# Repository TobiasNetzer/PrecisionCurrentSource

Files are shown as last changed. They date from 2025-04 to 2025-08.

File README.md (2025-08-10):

## A precision current source that can be configured for currents up to ~10mA.

I needed to verify the current measurement accuracy of the low-current ranges of my data logger and a reference for calibration purposes. Since I don’t own a programmable current source like a Keithley 220 or SMU, I came up with this approach instead. Check [here](https://tobiasnetzer.github.io/posts/current-source/) for more info.

Documentation
- [Schematic](https://github.com/TobiasNetzer/PrecisionCurrentSource/blob/main/Documentation/Schematic.pdf)
- [Assembly Drawing](https://github.com/TobiasNetzer/PrecisionCurrentSource/blob/main/Documentation/Assembly%20Drawing.pdf)
- [BOM](https://htmlpreview.github.io/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)

---

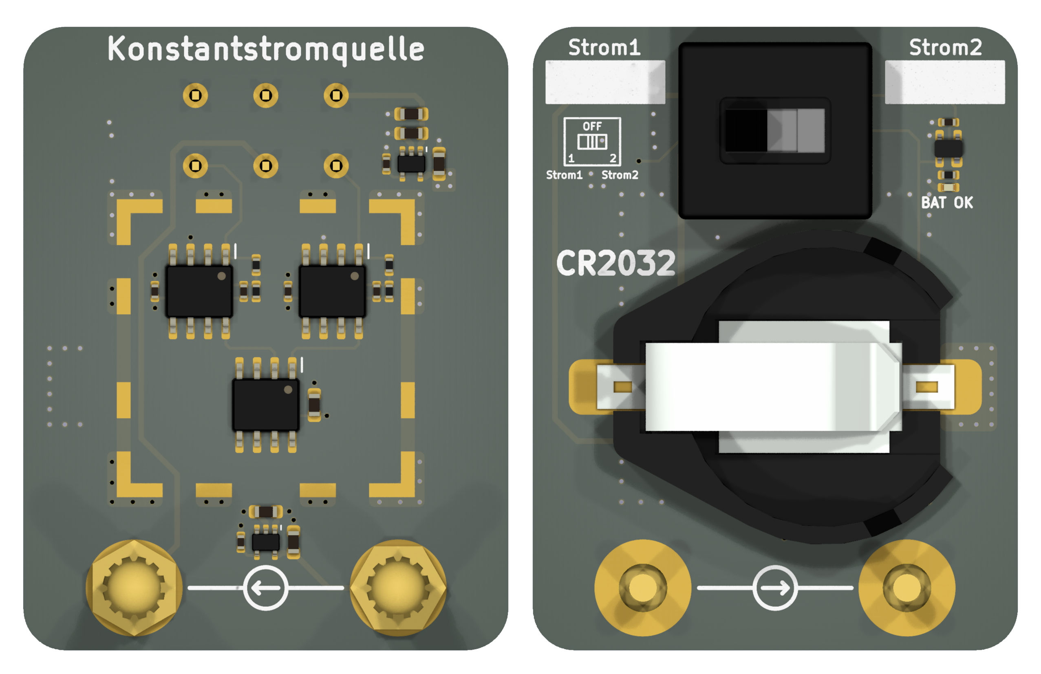
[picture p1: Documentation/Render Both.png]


## Limitations of the Design

Due to the high internal resistance of CR2032 coin cells, they are unable to deliver currents higher than approximately 15mA. This inherently limits the maximum output of the constant current source. However, it's not the only limiting factor. The op-amp used in the circuit can only sink up to 15mA, making the current source only suitable for output currents up to around 10mA.  

In addition, the voltage swing across the load is limited to 1.4V. For example, at a current of 1mA, the maximum  load is limited to 1.4kΩ. This further restricts the usable range of the current source.

These limitations should be taken into account when using this current source!

## First Tests

The design has not been fully tested yet! The output current has been measured to be within ±0.2%.

| Configured Current &nbsp; &nbsp; &nbsp; &nbsp; &nbsp; &nbsp; | Measured Current &nbsp; &nbsp; &nbsp; &nbsp; &nbsp; &nbsp; | Error &nbsp; &nbsp; &nbsp; &nbsp; &nbsp; &nbsp; |
| --- | --- | --- |
| 100nA | 99.82nA | -0.18% |
| 1µA | 0.999µA | -0.1% |
| 100µA | 100.07µA | 0.07% |
| 1mA | 0.999mA | -0.1% |

Several other aspects such as load regulation, temperature stability and ripple/noise should also be tested. However, I currently lack the equipment to accurately perform these tests.

I did sample the output current with my datalogger at 1kHz to get an idea of how noisy the current source is. These results should be taken with a grain of salt, since the logger’s ADC does some internal averaging and I don't have a known reference to test the logger against.

| Current Source &nbsp; &nbsp; &nbsp; &nbsp; &nbsp; &nbsp; | Peak-Peak Current &nbsp; &nbsp; &nbsp; &nbsp; &nbsp; &nbsp; |
| --- | --- |
| 1µA | 1.23nA |
| 100µA | 73.25nA |
| 1mA | 1.24µA |

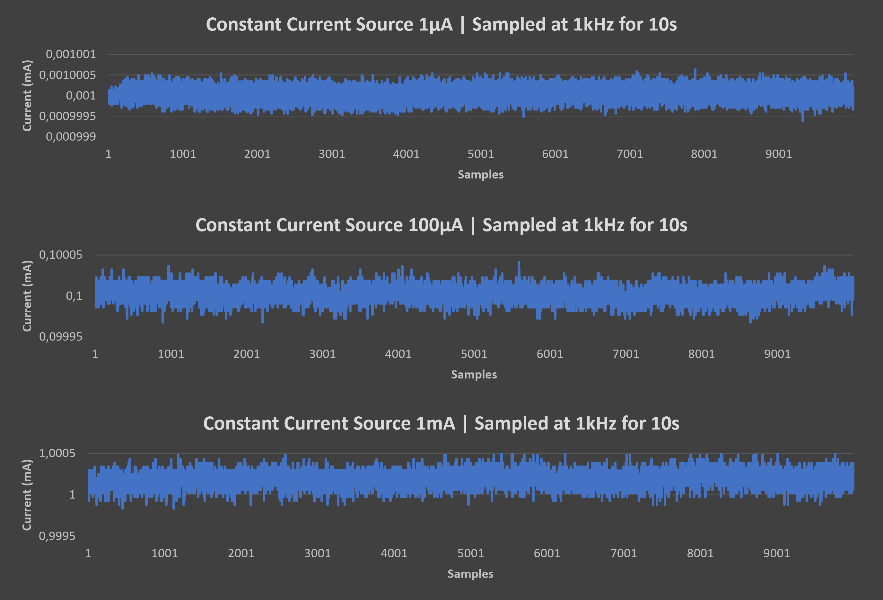
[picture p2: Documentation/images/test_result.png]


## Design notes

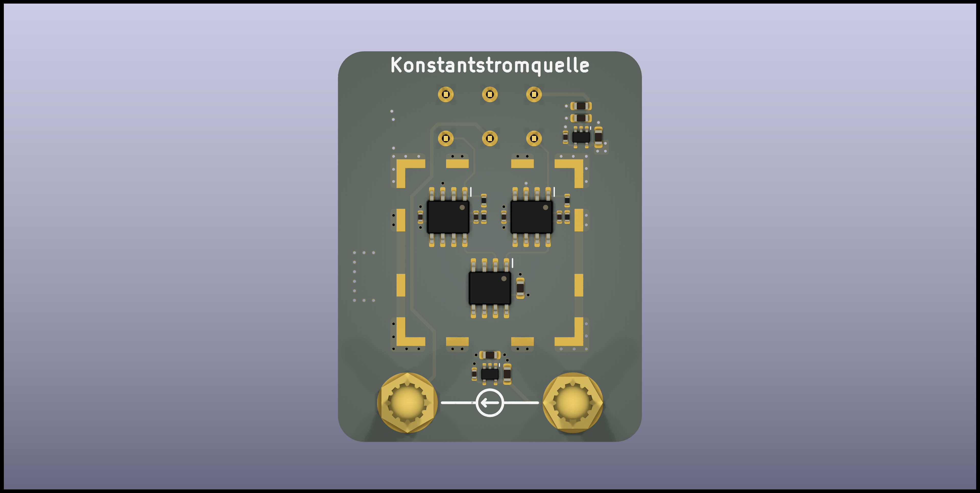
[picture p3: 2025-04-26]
Documentation/Render Top.png

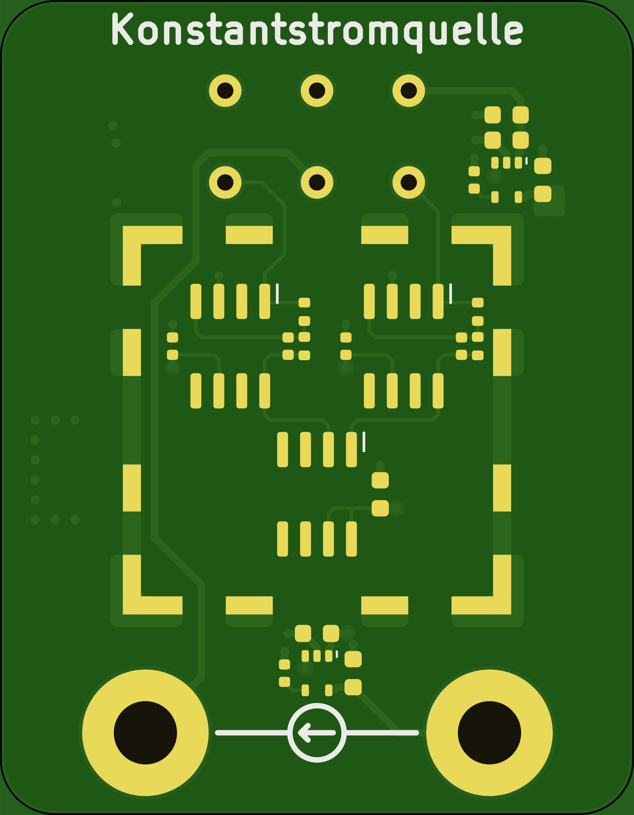
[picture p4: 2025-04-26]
Documentation/plot/PrecisionCurrentSource-Front.png

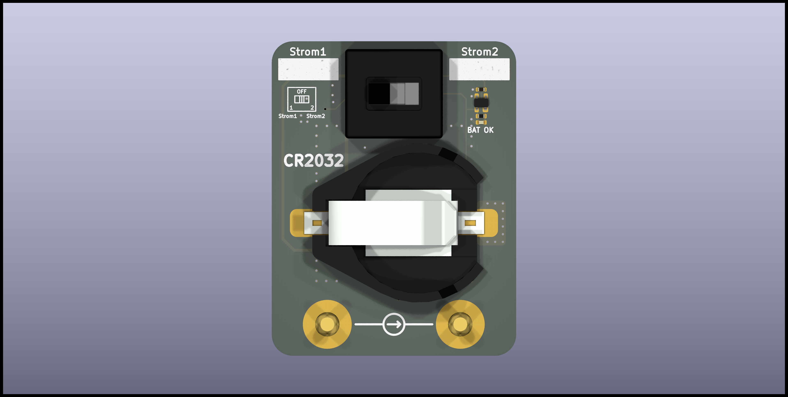
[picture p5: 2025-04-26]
Documentation/Render Bot.png

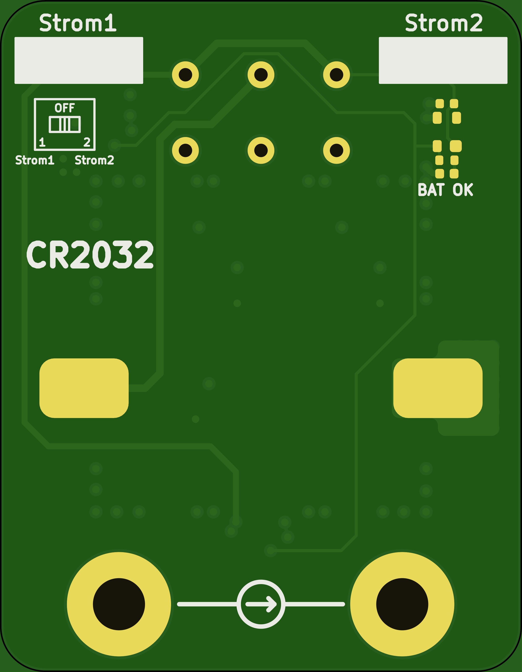
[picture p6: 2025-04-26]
Documentation/plot/PrecisionCurrentSource-Back.png

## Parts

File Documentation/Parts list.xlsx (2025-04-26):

Position | Menge | Reference(s) | Wert/Typ | Beschreibung | Hersteller | Hersteller-Nr. | Lieferant | Lieferant-Nr. | Stückpreis | Gesamtpreis
1 | 1 | BT1 | 2x CR2032 | Coin Cell Battery Holders 2X20MM SMT COIN HOLDER | Keystone Electronics | 1062 | Mouser | 534-1062 | 3.02 € | 3.02 €
2 | 2 | C1, C13 | 10µF | 10µF-20%-0603-X5R-10V | Kemet | C0603C106M8PACTU | Mouser | 80-C0603C106M8PACTU | 0.43 € | 0.86 €
3 | 3 | C2, C3, C5 | 100nF | 100nF-20%-0402-X7R-25V | Kemet | C0402C104M3RACTU | Mouser | 80-C0402C104M3R | 0.26 € | 0.78 €
4 | 4 | C4, C6, C8, C11 | 10nF | 10nF-10%-0402-X7R-50V | Kemet | C0402C103K5REC7411 | Mouser | 80-C0402C103K5RECLR | 0.10 € | 0.40 €
5 | 4 | C7, C9, C10, C12 | 1µF | 1µF-10%-0603-X7R-25V | Kemet | C0603C105K3RACTU | Mouser | 80-C0603C105K3R | 0.26 € | 1.04 €
6 | 1 | D1 | Green | LED Green 0402 | Kingbright | APHHS1005ZGC | Mouser | 604-APHHS1005ZGC | 0.66 € | 0.66 €
7 | 1 | J1 | EMI-Shield | EMI Gaskets, Sheets, Absorbers & Shielding WE-SHC SMD Frame 21x21mm | Würth Elektronik | 36103205 | Mouser | 710-36103205 | 2.90 € | 2.90 €
8 | 1 | R1 | 8k2 | 8k2-1%-0402-62.5mW-100ppm | Yageo | AC0402FR-138K2L | Mouser | 603-AC0402FR-138K2L | 0.09 € | 0.09 €
9 | 2 | R2, R4 | 1k 0,05% | 1k-0.05%-0402-62.5mW-5ppm | Susumu | RG1005V-102-W-T1 | Mouser | 754-RG1005V-102-WT1 | 3.12 € | 6.24 €
10 | 1 | R3 | 1M 0,1% | 1M-0.1%-0402-100mW-25ppm | Vishay | MCS0402MD1004BE000 | Mouser | 594-MCS0402MD1004BE0 | 0.66 € | 0.66 €
11 | 1 | R5 | 100k 0,05% | 100k-0.05%-0402-62.5mW-10ppm | Vishay | TNPU0402100KAYEP00 | Mouser | 71-TNPU0402100KAYEP0 | 1.56 € | 1.56 €
12 | 1 | SW1 | 600DP3S2M4R | Schiebeschalter DPDT Durchkontaktierung | E-Switch | 600DP3S2M4R | Digikey | 600DP3S2M4R-ND | 2.29 € | 2.29 €
13 | 1 | U1 | BU4947F | Supervisory Circuits IC CMOS VOLT DETECT | ROHM Semiconductor | BU4947F-TR | Mouser | 755-BU4947F-TR | 0.54 € | 0.54 €
14 | 2 | U2, U3 | LMP7721 | Präzisionsverstärker 3 FEMTOAMPERE INPUT BIAS CURR PREC AMP | Texas Instruments | LMP7721MA/NOPB | Mouser | 926-LMP7721MA/NOPB | 6.12 € | 12.24 €
15 | 1 | U4 | REF200AU | Strom- und Leistungswächter und -regler Dual Current Source Current Sink | Texas Instruments | REF200AU | Mouser | 595-REF200AU | 11.01 € | 11.01 €
16 | 1 | U5 | TPS71745 | LDO Voltage Regulators AC SGL Out LDO 150mA Fixed High PSRR | Texas Instruments | TPS71745QDCKRQ1 | Mouser | 595-TPS71745QDCKRQ1 | 1.44 € | 1.44 €
17 | 1 | U6 | TPS71715 | LDO Spannungs-Regulator LN High-BW PSRR 150mA | Texas Instruments | TPS71715DCKT | Mouser | 595-TPS71715DCKT | 1.46 € | 1.46 €
 |  |  |  |  |  |  |  |  |  | 47.19 €

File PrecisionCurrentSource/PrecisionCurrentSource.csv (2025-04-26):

Source: | X:\TA\Precision Current Source\PrecisionCurrentSource\PrecisionCurrentSource.kicad_sch
Date: | 19/04/2022 01:20:49
Tool: | Eeschema (6.0.4)
Generator: | C:\Program Files\KiCad\6.0\bin\scripting\plugins/bom_csv_grouped_by_value.py
Component Count: | 30
Individual Components:
Item | Qty | Reference(s) | Value | LibPart | Footprint | Datasheet | Beschreibung | Hersteller | Hersteller-Nr. | Lieferant | Lieferant-Nr.
 |  | BT1 | 2x CR2032 | PrecisionCurrentSource:Battery_Holder_1062 | PrecisionCurrentSource:Keystone_1062 | https://eu.mouser.com/datasheet/2/215/1062-745917.pdf | Coin Cell Battery Holders 2X20MM SMT COIN HOLDER | Keystone Electronics | 1062 | Mouser | 534-1062
 |  | C1 | 10µF | PrecisionCurrentSource:Capacitor_0603 | PrecisionCurrentSource:Capacitor_0603 | ~ | 10µF-20%-0603-X5R-10V | Kemet | C0603C106M8PACTU | Mouser | 80-C0603C106M8PACTU
 |  | C2 | 100nF | PrecisionCurrentSource:Capacitor_0402 | PrecisionCurrentSource:Capacitor_0402 | ~ | 100nF-20%-0402-X7R-25V | Kemet | C0402C104M3RACTU | Mouser | 80-C0402C104M3R
 |  | C3 | 100nF | PrecisionCurrentSource:Capacitor_0402 | PrecisionCurrentSource:Capacitor_0402 | ~ | 100nF-20%-0402-X7R-25V | Kemet | C0402C104M3RACTU | Mouser | 80-C0402C104M3R
 |  | C4 | 10nF | PrecisionCurrentSource:Capacitor_0402 | PrecisionCurrentSource:Capacitor_0402 | ~ | 10nF-10%-0402-X7R-50V | Kemet | C0402C103K5REC7411 | Mouser | 80-C0402C103K5RECLR
 |  | C5 | 100nF | PrecisionCurrentSource:Capacitor_0402 | PrecisionCurrentSource:Capacitor_0402 | ~ | 100nF-20%-0402-X7R-25V | Kemet | C0402C104M3RACTU | Mouser | 80-C0402C104M3R
 |  | C6 | 10nF | PrecisionCurrentSource:Capacitor_0402 | PrecisionCurrentSource:Capacitor_0402 | ~ | 10nF-10%-0402-X7R-50V | Kemet | C0402C103K5REC7411 | Mouser | 80-C0402C103K5RECLR
 |  | C7 | 1µF | PrecisionCurrentSource:Capacitor_0603 | PrecisionCurrentSource:Capacitor_0603 | ~ | 1µF-10%-0603-X7R-25V | Kemet | C0603C105K3RACTU | Mouser | 80-C0603C105K3R
 |  | C8 | 10nF | PrecisionCurrentSource:Capacitor_0402 | PrecisionCurrentSource:Capacitor_0402 | ~ | 10nF-10%-0402-X7R-50V | Kemet | C0402C103K5REC7411 | Mouser | 80-C0402C103K5RECLR
 |  | C9 | 1µF | PrecisionCurrentSource:Capacitor_0603 | PrecisionCurrentSource:Capacitor_0603 | ~ | 1µF-10%-0603-X7R-25V | Kemet | C0603C105K3RACTU | Mouser | 80-C0603C105K3R
 |  | C10 | 1µF | PrecisionCurrentSource:Capacitor_0603 | PrecisionCurrentSource:Capacitor_0603 | ~ | 1µF-10%-0603-X7R-25V | Kemet | C0603C105K3RACTU | Mouser | 80-C0603C105K3R
 |  | C11 | 10nF | PrecisionCurrentSource:Capacitor_0402 | PrecisionCurrentSource:Capacitor_0402 | ~ | 10nF-10%-0402-X7R-50V | Kemet | C0402C103K5REC7411 | Mouser | 80-C0402C103K5RECLR
 |  | C12 | 1µF | PrecisionCurrentSource:Capacitor_0603 | PrecisionCurrentSource:Capacitor_0603 | ~ | 1µF-10%-0603-X7R-25V | Kemet | C0603C105K3RACTU | Mouser | 80-C0603C105K3R
 |  | C13 | 10µF | PrecisionCurrentSource:Capacitor_0603 | PrecisionCurrentSource:Capacitor_0603 | ~ | 10µF-20%-0603-X5R-10V | Kemet | C0603C106M8PACTU | Mouser | 80-C0603C106M8PACTU
 |  | D1 | Green | PrecisionCurrentSource:LED_0402 | PrecisionCurrentSource:LED_0402 | ~ | LED Green 0402 | Kingbright | APHHS1005ZGC | Mouser | 604-APHHS1005ZGC
 |  | H1 | MountingHole | PrecisionCurrentSource:MountingHole | PrecisionCurrentSource:MountingHole | ~
 |  | H2 | MountingHole | PrecisionCurrentSource:MountingHole | PrecisionCurrentSource:MountingHole | ~
 |  | J1 | EMI-Shield | :EMI_Shield_1 | PrecisionCurrentSource:Wuerth_36103205_20x20mm | https://www.mouser.de/datasheet/2/445/36103205-1716387.pdf | EMI Gaskets, Sheets, Absorbers & Shielding WE-SHC SMD Frame 21x21mm | Würth Elektronik | 36103205 | Mouser | 710-36103205
 |  | R1 | 8k2 | PrecisionCurrentSource:Resistor_0402 | PrecisionCurrentSource:Resistor_0402 | ~ | 8k2-1%-0402-62.5mW-100ppm | Yageo | AC0402FR-138K2L | Mouser | 603-AC0402FR-138K2L
 |  | R2 | 1k 0,05% | PrecisionCurrentSource:Resistor_0402 | PrecisionCurrentSource:Resistor_0402 | ~ | 1k-0.05%-0402-62.5mW-5ppm | Susumu | RG1005V-102-W-T1 | Mouser | 754-RG1005V-102-WT1
 |  | R3 | 1M 0,1% | PrecisionCurrentSource:Resistor_0402 | PrecisionCurrentSource:Resistor_0402 | ~ | 1M-0.1%-0402-100mW-25ppm | Vishay | MCS0402MD1004BE000 | Mouser | 594-MCS0402MD1004BE0
 |  | R4 | 1k 0,05% | PrecisionCurrentSource:Resistor_0402 | PrecisionCurrentSource:Resistor_0402 | ~ | 1k-0.05%-0402-62.5mW-5ppm | Susumu | RG1005V-102-W-T1 | Mouser | 754-RG1005V-102-WT1
 |  | R5 | 100k 0,05% | PrecisionCurrentSource:Resistor_0402 | PrecisionCurrentSource:Resistor_0402 | ~ | 100k-0.05%-0402-62.5mW-10ppm | Vishay | TNPU0402100KAYEP00 | Mouser | 71-TNPU0402100KAYEP0
 |  | SW1 | 600DP3S2M4R | PrecisionCurrentSource:600DP3S2M4R | PrecisionCurrentSource:600DP3S2M4R | http://spec_sheets.e-switch.com/specs/T620307.pdf | Schiebeschalter DPDT Durchkontaktierung | E-Switch | 600DP3S2M4R | Digikey | 600DP3S2M4R-ND
 |  | U1 | BU4947F | PrecisionCurrentSource:BU4947F | PrecisionCurrentSource:SOP4 | https://www.mouser.de/datasheet/2/348/bu48xxg_e-1874410.pdf | Supervisory Circuits IC CMOS VOLT DETECT | ROHM Semiconductor | BU4947F-TR | Mouser | 755-BU4947F-TR
 |  | U2 | LMP7721 | PrecisionCurrentSource:LMP7721 | PrecisionCurrentSource:SOIC-8 | https://www.ti.com/lit/ds/symlink/lmp7721.pdf?HQS=dis-mous-null-mousermode-dsf-pf-null-wwe&ts=1633781774392 | Präzisionsverstärker 3 FEMTOAMPERE INPUT BIAS CURR PREC AMP | Texas Instruments | LMP7721MA/NOPB | Mouser | 926-LMP7721MA/NOPB
 |  | U3 | LMP7721 | PrecisionCurrentSource:LMP7721 | PrecisionCurrentSource:SOIC-8 | https://www.ti.com/lit/ds/symlink/lmp7721.pdf?HQS=dis-mous-null-mousermode-dsf-pf-null-wwe&ts=1633781774392 | Präzisionsverstärker 3 FEMTOAMPERE INPUT BIAS CURR PREC AMP | Texas Instruments | LMP7721MA/NOPB | Mouser | 926-LMP7721MA/NOPB
 |  | U4 | REF200AU | PrecisionCurrentSource:REF200AU | PrecisionCurrentSource:SOIC-8 | https://www.ti.com/lit/ds/symlink/ref200.pdf?ts=1633768165003 | Strom- und Leistungswächter und -regler Dual Current Source Current Sink | Texas Instruments | REF200AU | Mouser | 595-REF200AU
 |  | U5 | TPS71745 | PrecisionCurrentSource:TPS71745 | PrecisionCurrentSource:SC70-5 | https://www.ti.com/general/docs/suppproductinfo.tsp?distId=26 | LDO Voltage Regulators AC SGL Out LDO 150mA Fixed High PSRR | Texas Instruments | TPS71745QDCKRQ1 | Mouser | 595-TPS71745QDCKRQ1
 |  | U6 | TPS71715 | PrecisionCurrentSource:TPS71715 | PrecisionCurrentSource:SC70-5 | https://www.ti.com/lit/ds/symlink/tps717.pdf?HQS=dis-mous-null-mousermode-dsf-pf-null-wwe&ts=1636293424450 | LDO Spannungs-Regulator LN High-BW PSRR 150mA | Texas Instruments | TPS71715DCKT | Mouser | 595-TPS71715DCKT
Collated Components:
Item | Qty | Reference(s) | Value | LibPart | Footprint | Datasheet | Beschreibung | Hersteller | Hersteller-Nr. | Lieferant | Lieferant-Nr.
1 | 1 | BT1 | 2x CR2032 | PrecisionCurrentSource:Battery_Holder_1062 | PrecisionCurrentSource:Keystone_1062 | https://eu.mouser.com/datasheet/2/215/1062-745917.pdf | Coin Cell Battery Holders 2X20MM SMT COIN HOLDER | Keystone Electronics | 1062 | Mouser | 534-1062
2 | 2 | C1, C13 | 10µF | PrecisionCurrentSource:Capacitor_0603 | PrecisionCurrentSource:Capacitor_0603 | ~ | 10µF-20%-0603-X5R-10V | Kemet | C0603C106M8PACTU | Mouser | 80-C0603C106M8PACTU
3 | 3 | C2, C3, C5 | 100nF | PrecisionCurrentSource:Capacitor_0402 | PrecisionCurrentSource:Capacitor_0402 | ~ | 100nF-20%-0402-X7R-25V | Kemet | C0402C104M3RACTU | Mouser | 80-C0402C104M3R
4 | 4 | C4, C6, C8, C11 | 10nF | PrecisionCurrentSource:Capacitor_0402 | PrecisionCurrentSource:Capacitor_0402 | ~ | 10nF-10%-0402-X7R-50V | Kemet | C0402C103K5REC7411 | Mouser | 80-C0402C103K5RECLR
5 | 4 | C7, C9, C10, C12 | 1µF | PrecisionCurrentSource:Capacitor_0603 | PrecisionCurrentSource:Capacitor_0603 | ~ | 1µF-10%-0603-X7R-25V | Kemet | C0603C105K3RACTU | Mouser | 80-C0603C105K3R
6 | 1 | D1 | Green | PrecisionCurrentSource:LED_0402 | PrecisionCurrentSource:LED_0402 | ~ | LED Green 0402 | Kingbright | APHHS1005ZGC | Mouser | 604-APHHS1005ZGC
7 | 2 | H1, H2 | MountingHole | PrecisionCurrentSource:MountingHole | PrecisionCurrentSource:MountingHole | ~
8 | 1 | J1 | EMI-Shield | :EMI_Shield_1 | PrecisionCurrentSource:Wuerth_36103205_20x20mm | https://www.mouser.de/datasheet/2/445/36103205-1716387.pdf | EMI Gaskets, Sheets, Absorbers & Shielding WE-SHC SMD Frame 21x21mm | Würth Elektronik | 36103205 | Mouser | 710-36103205
9 | 1 | R1 | 8k2 | PrecisionCurrentSource:Resistor_0402 | PrecisionCurrentSource:Resistor_0402 | ~ | 8k2-1%-0402-62.5mW-100ppm | Yageo | AC0402FR-138K2L | Mouser | 603-AC0402FR-138K2L
10 | 2 | R2, R4 | 1k 0,05% | PrecisionCurrentSource:Resistor_0402 | PrecisionCurrentSource:Resistor_0402 | ~ | 1k-0.05%-0402-62.5mW-5ppm | Susumu | RG1005V-102-W-T1 | Mouser | 754-RG1005V-102-WT1
11 | 1 | R3 | 1M 0,1% | PrecisionCurrentSource:Resistor_0402 | PrecisionCurrentSource:Resistor_0402 | ~ | 1M-0.1%-0402-100mW-25ppm | Vishay | MCS0402MD1004BE000 | Mouser | 594-MCS0402MD1004BE0
12 | 1 | R5 | 100k 0,05% | PrecisionCurrentSource:Resistor_0402 | PrecisionCurrentSource:Resistor_0402 | ~ | 100k-0.05%-0402-62.5mW-10ppm | Vishay | TNPU0402100KAYEP00 | Mouser | 71-TNPU0402100KAYEP0
13 | 1 | SW1 | 600DP3S2M4R | PrecisionCurrentSource:600DP3S2M4R | PrecisionCurrentSource:600DP3S2M4R | http://spec_sheets.e-switch.com/specs/T620307.pdf | Schiebeschalter DPDT Durchkontaktierung | E-Switch | 600DP3S2M4R | Digikey | 600DP3S2M4R-ND
14 | 1 | U1 | BU4947F | PrecisionCurrentSource:BU4947F | PrecisionCurrentSource:SOP4 | https://www.mouser.de/datasheet/2/348/bu48xxg_e-1874410.pdf | Supervisory Circuits IC CMOS VOLT DETECT | ROHM Semiconductor | BU4947F-TR | Mouser | 755-BU4947F-TR
15 | 2 | U2, U3 | LMP7721 | PrecisionCurrentSource:LMP7721 | PrecisionCurrentSource:SOIC-8 | https://www.ti.com/lit/ds/symlink/lmp7721.pdf?HQS=dis-mous-null-mousermode-dsf-pf-null-wwe&ts=1633781774392 | Präzisionsverstärker 3 FEMTOAMPERE INPUT BIAS CURR PREC AMP | Texas Instruments | LMP7721MA/NOPB | Mouser | 926-LMP7721MA/NOPB
16 | 1 | U4 | REF200AU | PrecisionCurrentSource:REF200AU | PrecisionCurrentSource:SOIC-8 | https://www.ti.com/lit/ds/symlink/ref200.pdf?ts=1633768165003 | Strom- und Leistungswächter und -regler Dual Current Source Current Sink | Texas Instruments | REF200AU | Mouser | 595-REF200AU
17 | 1 | U5 | TPS71745 | PrecisionCurrentSource:TPS71745 | PrecisionCurrentSource:SC70-5 | https://www.ti.com/general/docs/suppproductinfo.tsp?distId=26 | LDO Voltage Regulators AC SGL Out LDO 150mA Fixed High PSRR | Texas Instruments | TPS71745QDCKRQ1 | Mouser | 595-TPS71745QDCKRQ1
18 | 1 | U6 | TPS71715 | PrecisionCurrentSource:TPS71715 | PrecisionCurrentSource:SC70-5 | https://www.ti.com/lit/ds/symlink/tps717.pdf?HQS=dis-mous-null-mousermode-dsf-pf-null-wwe&ts=1636293424450 | LDO Spannungs-Regulator LN High-BW PSRR 150mA | Texas Instruments | TPS71715DCKT | Mouser | 595-TPS71715DCKT

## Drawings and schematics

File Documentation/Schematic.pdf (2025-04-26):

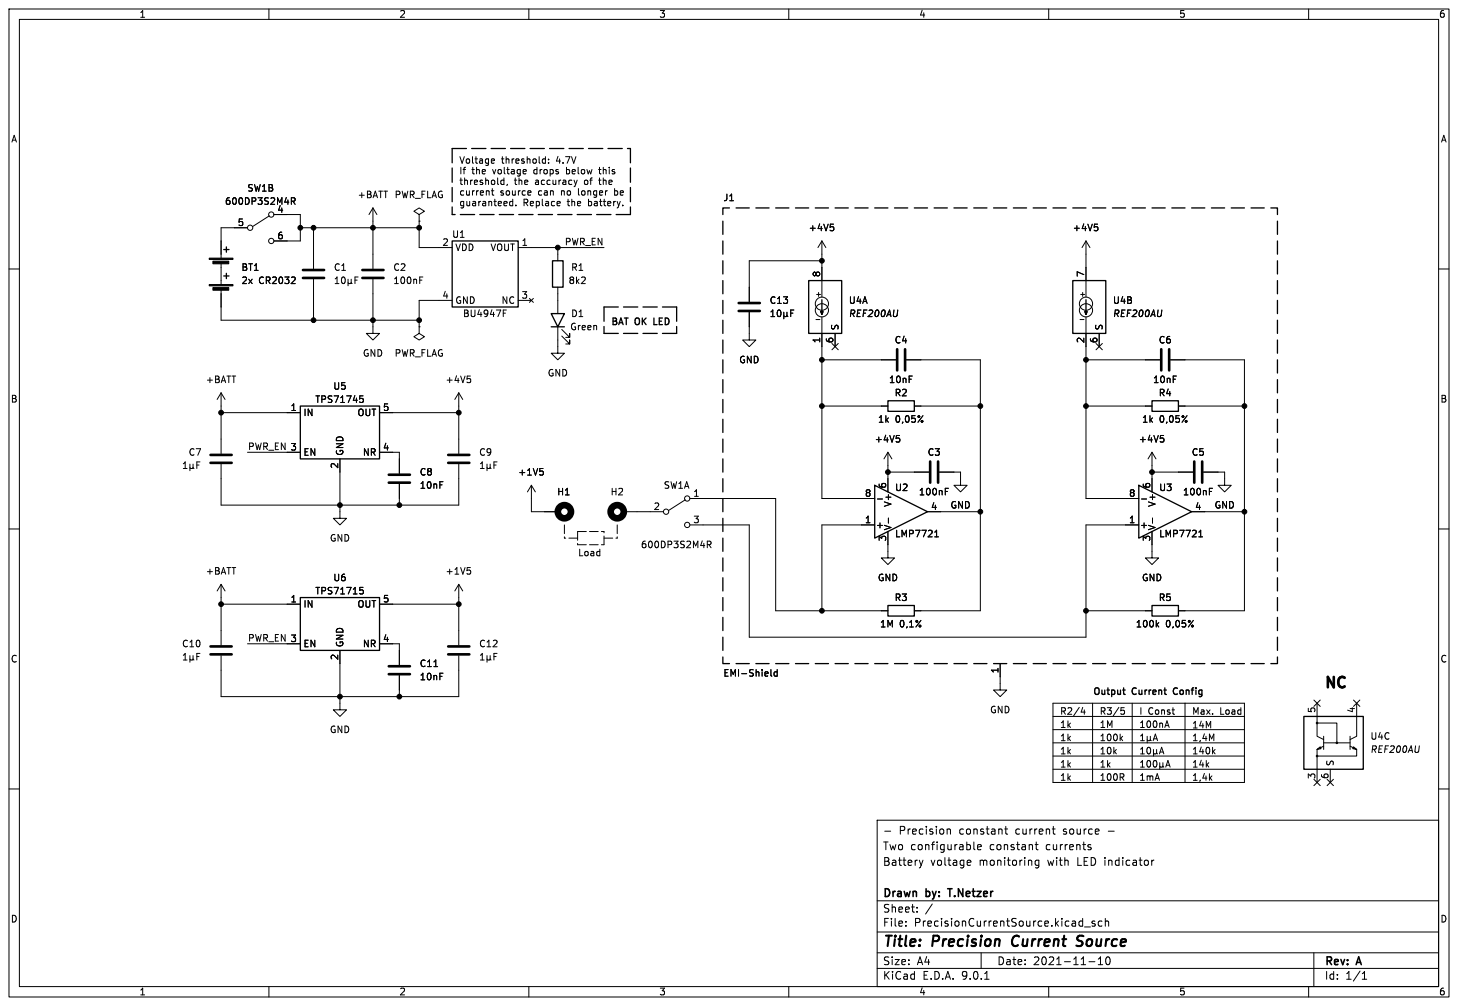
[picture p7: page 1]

If the voltage drops below this
current source can no longer be

2 OUT 5 NR 4 U5 TPS71745 VDD 2 GND 4 VOUT 1 NC 3 U1BU4947F PWR_FLAG

Id: 1/1 Title: Precision Current Source

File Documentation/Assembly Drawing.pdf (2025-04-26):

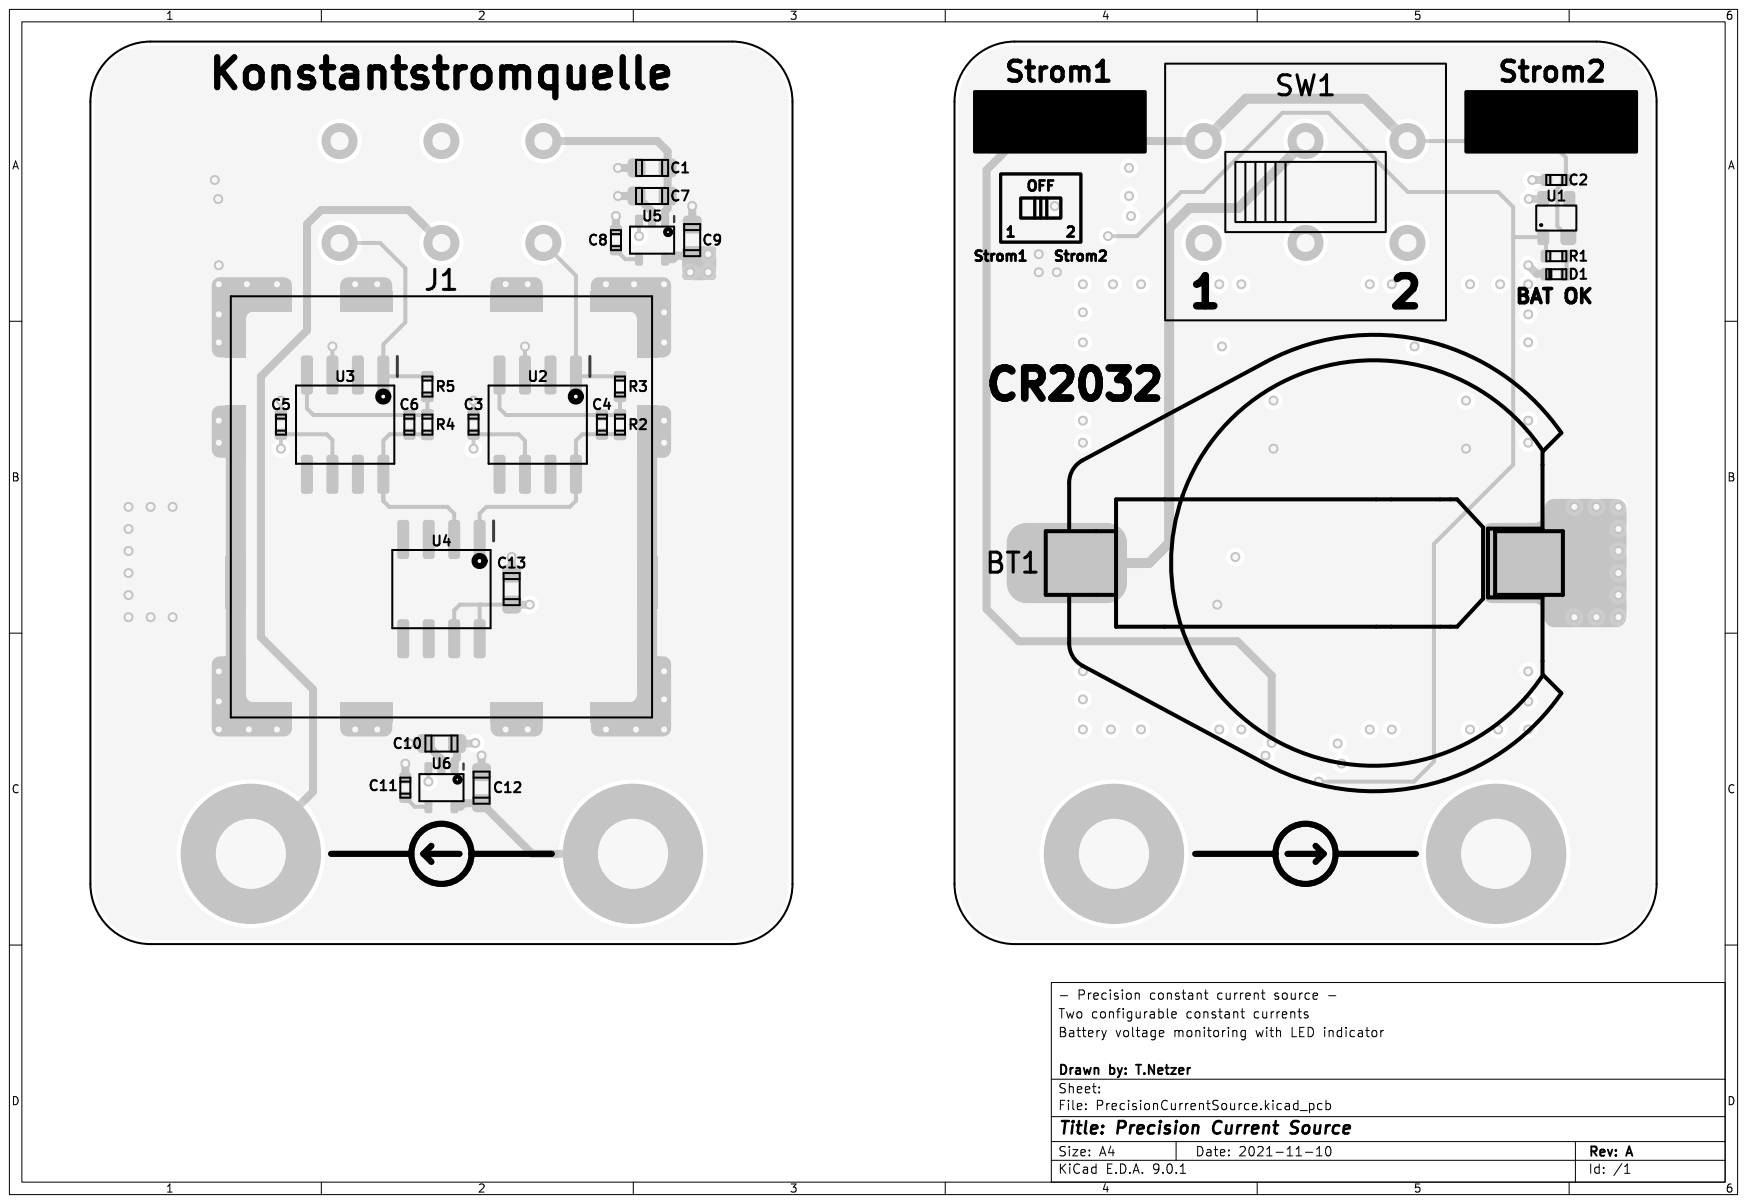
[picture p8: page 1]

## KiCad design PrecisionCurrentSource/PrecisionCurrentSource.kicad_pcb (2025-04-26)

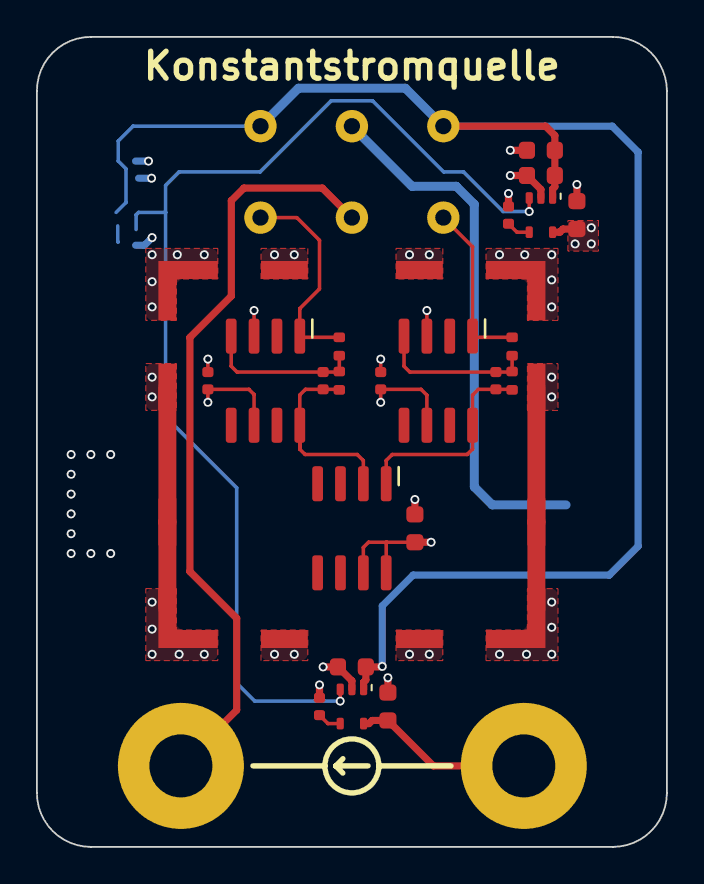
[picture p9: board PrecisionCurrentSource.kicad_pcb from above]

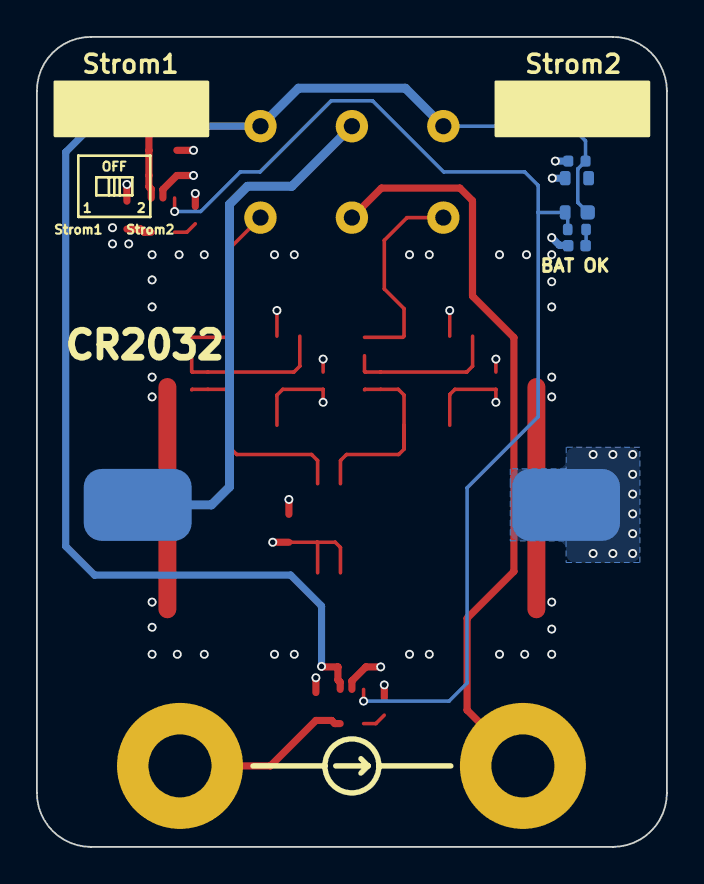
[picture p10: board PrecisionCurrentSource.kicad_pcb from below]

Board: 4 copper layers, 35.0 x 45.0 mm, 30 parts (6 on the bottom side), 16 nets.

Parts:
BT1: 2x CR2032; Keystone_1062
C1, C13: 10µF; Capacitor_0603
C2, C3, C5: 100nF; Capacitor_0402
C4, C6, C8, C11: 10nF; Capacitor_0402
C7, C9, C10, C12: 1µF; Capacitor_0603
D1: Green; LED_0402
H1, H2: MountingHole
J1: EMI-Shield; Wuerth_36103205_20x20mm
R1: 8k2; Resistor_0402
R2, R4: 1k 0,05%; Resistor_0402
R3: 1M 0,1%; Resistor_0402
R5: 100k 0,05%; Resistor_0402
SW1: 600DP3S2M4R
U1: BU4947F; SOP4
U2, U3: LMP7721; SOIC-8
U4: REF200AU; SOIC-8
U5: TPS71745; SC70-5
U6: TPS71715; SC70-5

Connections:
+1V5: C12.1, H1.1, U6.5 (OUT)
+4V5: C3.1, C5.1, C9.1, C13.1, U2.6 (V+), U3.6 (V+), U4.7, U4.8, U5.5 (OUT)
+BATT: C1.1, C2.1, C7.1, C10.1, SW1.4 (A), SW1.6 (C), U1.2 (VDD), U5.1 (IN), U6.1 (IN)
/PWR_EN: R1.1, U1.1 (VOUT), U5.3 (EN), U6.3 (EN)
GND: BT1.2 (-), C1.2, C2.2, C3.2, C5.2, C7.2, C8.2, C9.2, C10.2, C11.2, C12.2, C13.2, D1.1 (K), J1.1 (Shield), U1.4 (GND), U2.3 (V-), U3.3 (V-), U5.2 (GND), U6.2 (GND)
unnamed: BT1.1 (+), SW1.5 (B)
unnamed: C4.2, R2.2, R3.2, U2.4
unnamed: C6.2, R4.2, R5.2, U3.4
unnamed: D1.2 (A), R1.2
unnamed: R3.1, SW1.1 (A), U2.1 (+)
unnamed: H2.1, SW1.2 (B)
unnamed: R5.1, SW1.3 (C), U3.1 (+)
unnamed: C4.1, R2.1, U2.8 (-), U4.1
unnamed: C6.1, R4.1, U3.8 (-), U4.2
unnamed: C8.1, U5.4 (NR)
unnamed: C11.1, U6.4 (NR)
